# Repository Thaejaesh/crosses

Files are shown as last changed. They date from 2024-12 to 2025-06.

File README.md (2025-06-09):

# FORKED FROM ORIGINAL CREATOR: Good-Great-Grand-Wonderful @ https://github.com/Good-Great-Grand-Wonderful/crosses
# Crosses
_DSF2417

A modular ergonomic columar staggered keyboard by Good Great Grand Wonderful LLC. 

Made with a precise trackball sensor. Eliminating the need to have another pointing device, everything is within reach.

Available at http://ergokeyboards.com

### Features

- Matrix with a thumb cluster that works better with our opposable thumbs!
- Main matrix layouts of: 3x5, 3x6, and 4x6
- Kailh Choc hotswap sockets, so you can explore and find your perfect switch
- Left/Right or dualing trackballs
- Optional OLED screens

### Firmware

QMK: https://github.com/Good-Great-Grand-Wonderful/qmk_firmware/tree/gggw/crosses

Vial: https://github.com/Good-Great-Grand-Wonderful/crosses-vial-qmk/tree/gggw/crosses

ZMK(testing): https://github.com/Good-Great-Grand-Wonderful/crosses-zmk

### Gerbers

Production ready and prepped with JLCPCB part numbers: [Gerbers](Gerbers)

### BOM

#### Cases

N = Number of trackballs

| Qty |3x5 | 3x6 | 4x6 | Item | Notes |
|---|----|-----|-----|---|---|
| 24 | x  | x | x | 3mm Heat set inserts | |
| 16 | x  | x | x | 3mm x 5mm Hex Bolts | +2 for every trackball you delete |
| 2xN | x  | x | x | 3mm x 12mm Hex Bolts | |
| 2xN | x  | x | x | 3mm x 8mm Hex Bolts | |
| 1 | x  | x | x | Thumb Cluster PCB Panel | |
| 4 | x  | x | x | Hirose FH12-14S 0.5SH 1x14 1MP P0.50mm Horizontal | |
| 2 | x  | x | x | SM06B-SRSS-TB(LF)(SN) | |
| 1 | x  | | | 3x5 Matrix PCB Panel | |
| 1 | | x | | 3x6 Matrix PCB Panel | |
| 1 | | | x | 4x6 Matrix PCB Panel | |
| 2 | x  | | | 100mm 14p 0.5mm pitch FFC cables | |
| 2 | | x | x | 150mm 14p 0.5mm pitch FFC cables | |
| 1xN | x  | x | x | 100mm 6p JST SH 1.0 Same direction cables | |
| 2x | x  | x | x | Thumb Cluster Case (one should be flipped) | |
| 2x | x  | | | 3x5 Matrix Case (one should be flipped) | |
| 2x | | x | | 3x6 Matrix Case (one should be flipped) | |
| 2x | | | x | 4x6 Matrix Case (one should be flipped) | |
| 36x | x  | | | Kailh Choc Hotswap Sockets | |
| 42x | | x | | Kailh Choc Hotswap Sockets | |
| 54x | | | x | Kailh Choc Hotswap Sockets | |
| 36x | x  | | | 1N4148 SMD SOD-123 Resistors | |
| 42x | | x | | 1N4148 SMD SOD-123 Resistors | |
| 54x | | | x | 1N4148 SMD SOD-123 Resistors | |
| 1xN | x  | x | x | Trackball Mount (one should be flipped) | |
| 1xN | x  | x | x | Trackball PCB | [Repo](https://github.com/Good-Great-Grand-Wonderful/PMW3360DM-T2QU) |
| 1xN | x  | x | x | PMW3360DM-T2QU + LM19-LSI | or sub a PMW3389 |
| 1xN | x  | x | x | Trackball Carrier Base | |
| 1xN | x  | x | x | Trackball Carrier Top | |

## License



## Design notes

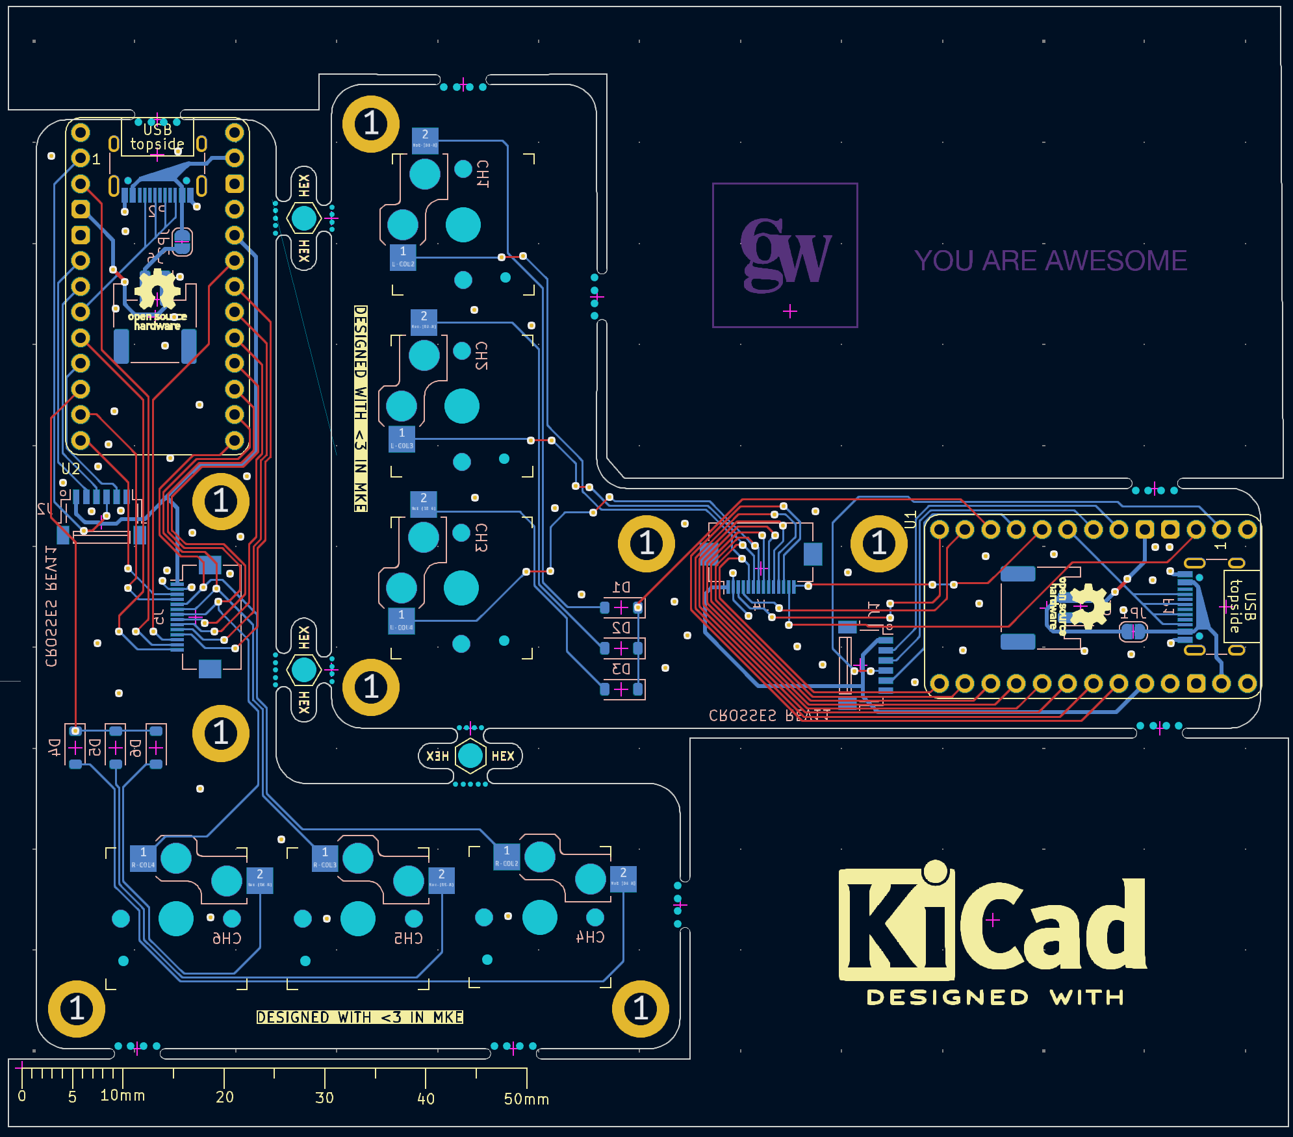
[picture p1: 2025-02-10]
Gerbers/thumbs-rev2-firmware-alpha/R11.png

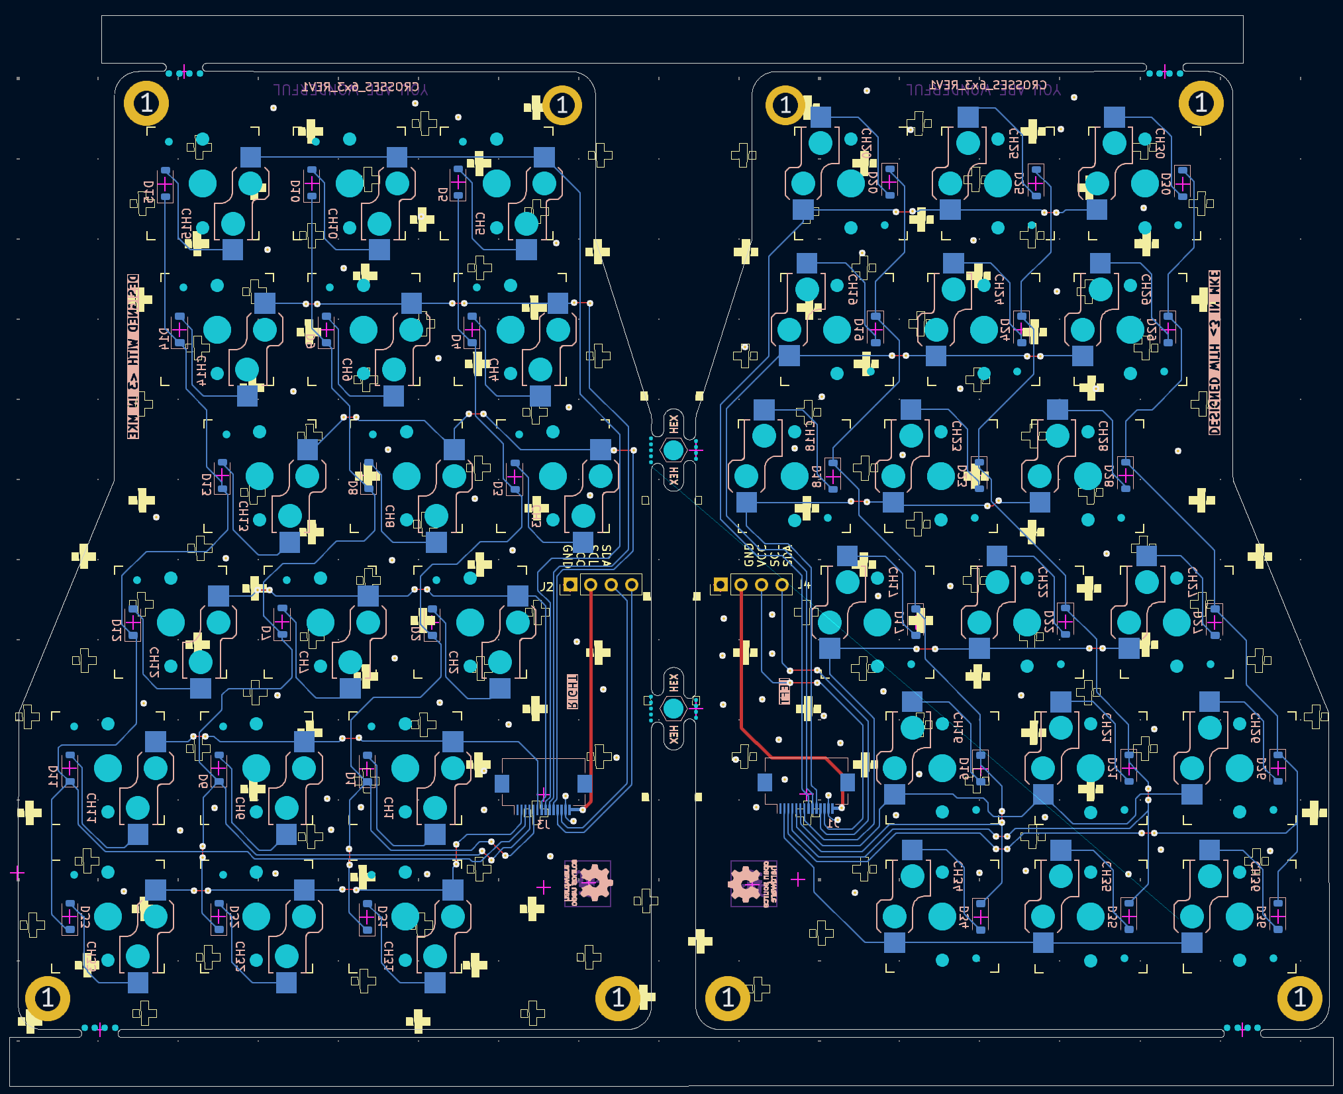
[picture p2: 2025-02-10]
Gerbers/matrix-6x3/6x3.png

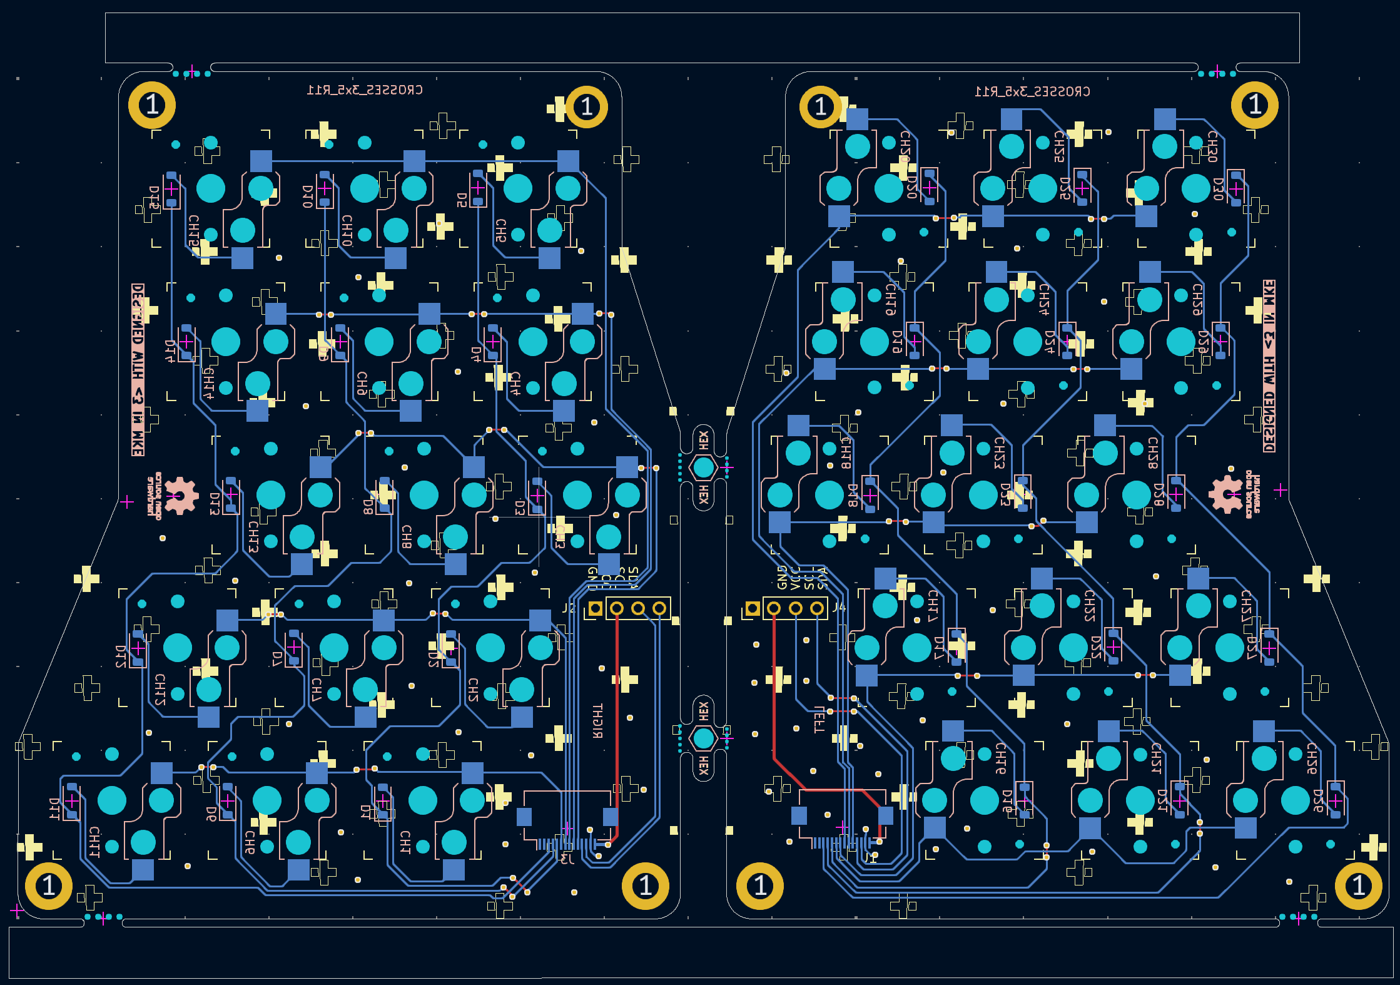
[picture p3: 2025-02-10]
Gerbers/matrix-5x3/5x3.png

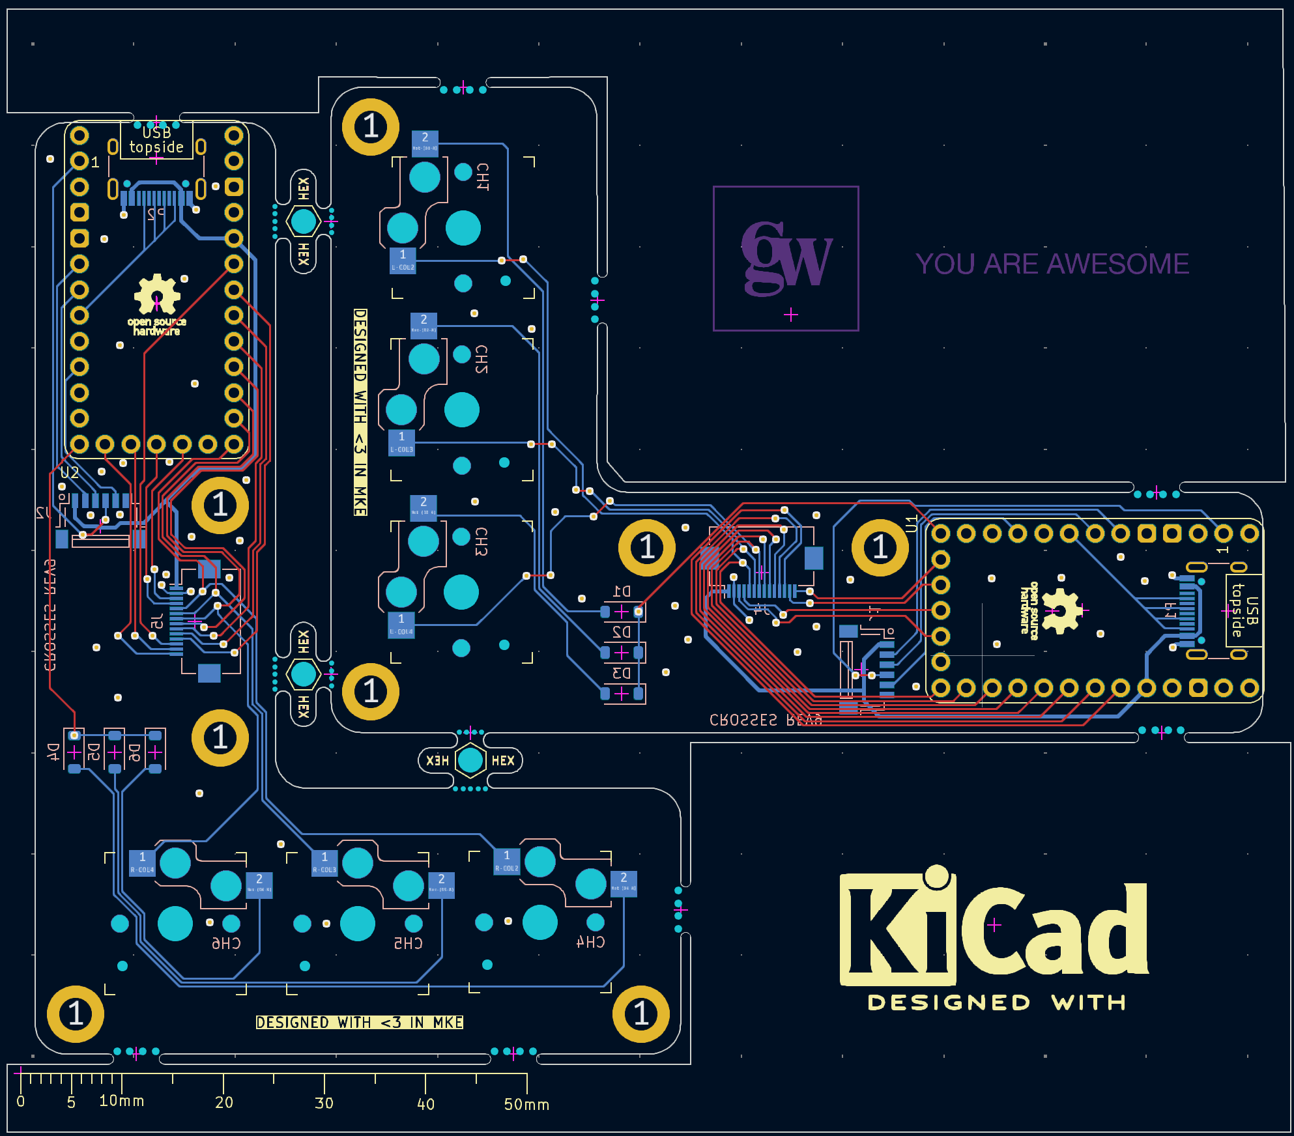
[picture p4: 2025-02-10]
Gerbers/thumbs-rev1-firmware/Rev9.png

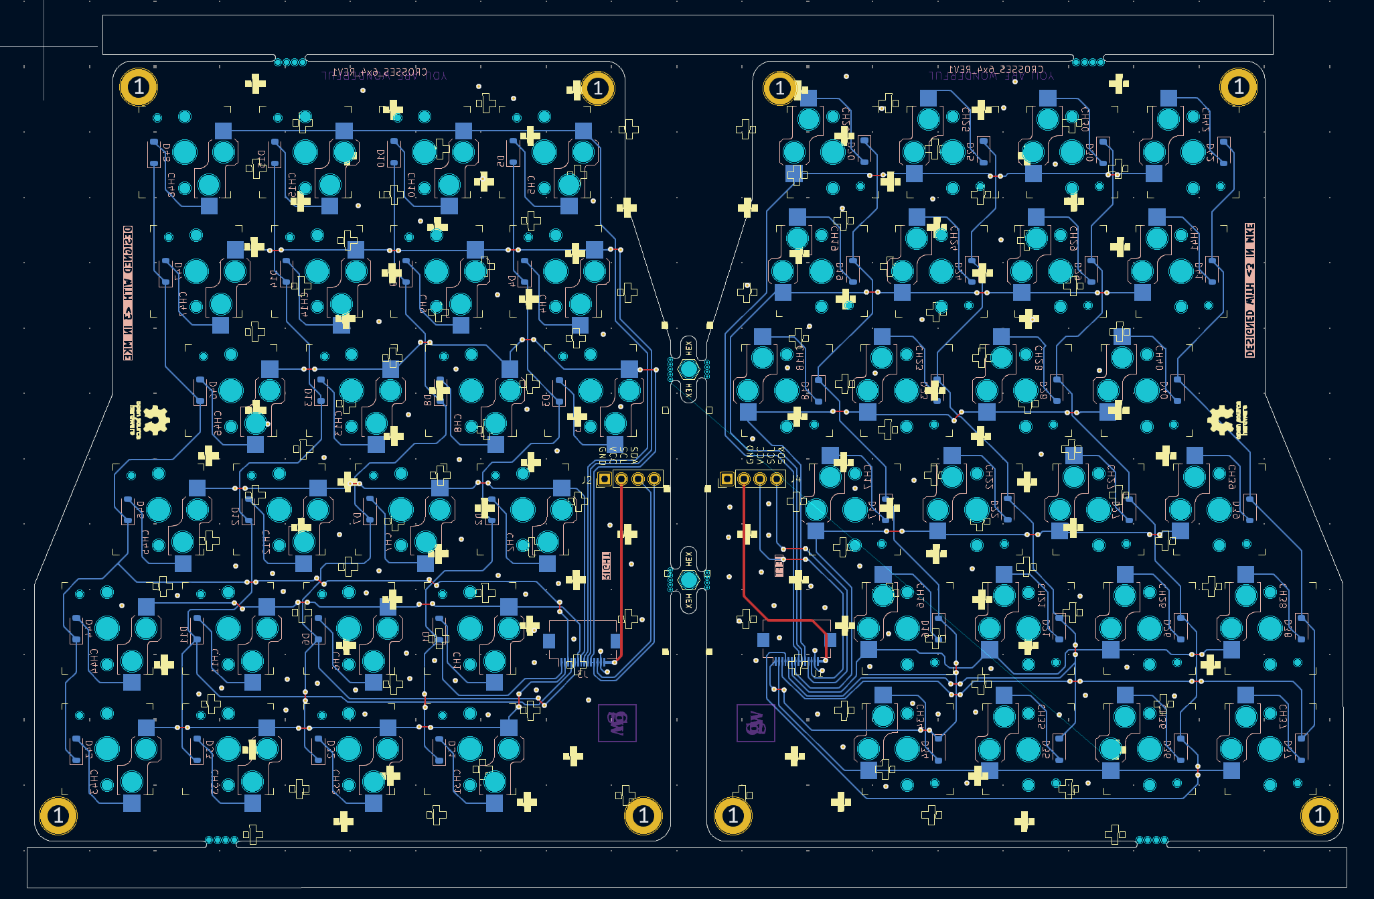
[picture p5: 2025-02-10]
Gerbers/matrix-6x4/6x4.png

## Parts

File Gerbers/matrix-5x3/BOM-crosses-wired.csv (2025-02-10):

Comment | Designator | Footprint | LCSC | Quantity
Conn_01x14_Pin | J1,J3 | Hirose_FH12-14S-0.5SH_1x14-1MP_P0.50mm_Horizontal | C5378715 | 2
1N4148 | D1,D10,D11,D12,D13,D14,D15,D16,D17,D18,D19,D2,D20,D21,D22,D23,D24,D25,D26,D27,D28,D29,D3,D30,D4,D5,D6,D7,D8,D9 | D_SOD-123 | C81598 | 30

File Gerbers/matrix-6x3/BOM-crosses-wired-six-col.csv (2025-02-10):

Comment | Designator | Footprint | LCSC | Quantity
Conn_01x14_Pin | J1,J3 | Hirose_FH12-14S-0.5SH_1x14-1MP_P0.50mm_Horizontal | C5378715 | 2
1N4148 | D1,D10,D11,D12,D13,D14,D15,D16,D17,D18,D19,D2,D20,D21,D22,D23,D24,D25,D26,D27,D28,D29,D3,D30,D31,D32,D33,D34,D35,D36,D4,D5,D6,D7,D8,D9 | D_SOD-123 | C81598 | 36
MountingHole | H3 | MountingHole_3.2mm_M3_DIN965_Pad |  | 1
MountingHole | H1 | MountingHole_3.2mm_M3_DIN965_Pad |  | 1
MountingHole | H6 | MountingHole_3.2mm_M3_DIN965_Pad |  | 1
MountingHole | H5 | MountingHole_3.2mm_M3_DIN965_Pad |  | 1

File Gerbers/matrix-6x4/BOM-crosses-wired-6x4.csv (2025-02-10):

Comment | Designator | Footprint | LCSC | Quantity
Conn_01x14_Pin | J1,J3 | Hirose_FH12-14S-0.5SH_1x14-1MP_P0.50mm_Horizontal | C5378715 | 2
1N4148 | D1,D10,D11,D12,D13,D14,D15,D16,D17,D18,D19,D2,D20,D21,D22,D23,D24,D25,D26,D27,D28,D29,D3,D30,D31,D32,D33,D34,D35,D36,D37,D38,D39,D4,D40,D41,D42,D43,D44,D45,D46,D47,D48,D5,D6,D7,D8,D9 | D_SOD-123 | C81598 | 48
MountingHole | H3 | MountingHole_3.2mm_M3_DIN965_Pad |  | 1
MountingHole | H1 | MountingHole_3.2mm_M3_DIN965_Pad |  | 1
MountingHole | H6 | MountingHole_3.2mm_M3_DIN965_Pad |  | 1
MountingHole | H5 | MountingHole_3.2mm_M3_DIN965_Pad |  | 1

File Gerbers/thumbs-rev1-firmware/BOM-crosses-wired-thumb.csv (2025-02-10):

Comment | Designator | Footprint | LCSC | Quantity
TYPE-C-31-M-12 USB | P1,P2 | USB_C_Receptacle_HRO_TYPE-C-31-M-12 | C165948 | 2
Conn_01x14_Pin | J4,J5 | Hirose_FH12-14S-0.5SH_1x14-1MP_P0.50mm_Horizontal | C5378715 | 2
1N4148 | D1,D2,D3,D4,D5,D6 | D_SOD-123 | C81598 | 6
MountingHole | H3 | MountingHole_3.2mm_M3_DIN965_Pad |  | 1
MountingHole | H1 | MountingHole_3.2mm_M3_DIN965_Pad |  | 1
MountingHole | H2 | MountingHole_3.2mm_M3_DIN965_Pad |  | 1

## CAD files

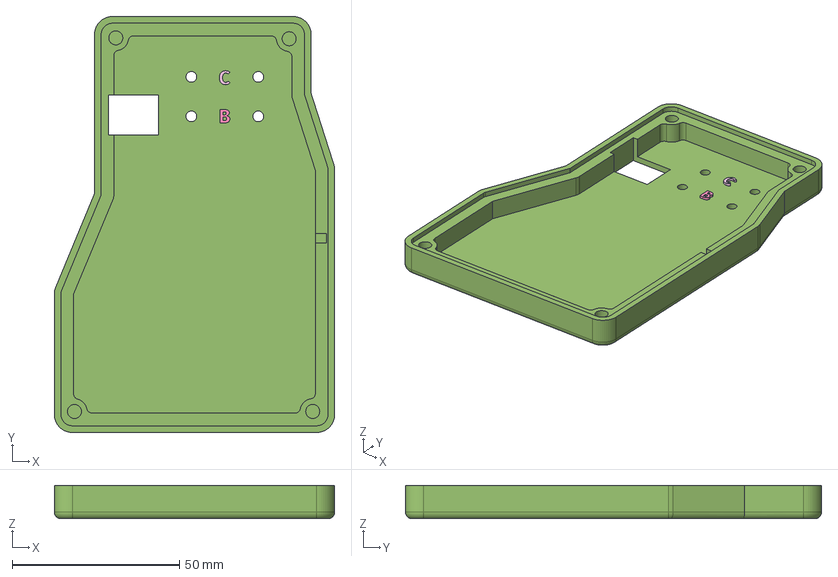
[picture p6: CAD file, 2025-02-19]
models/MatrixCase-3x6.step
83.8 x 124.3 x 10.0 mm

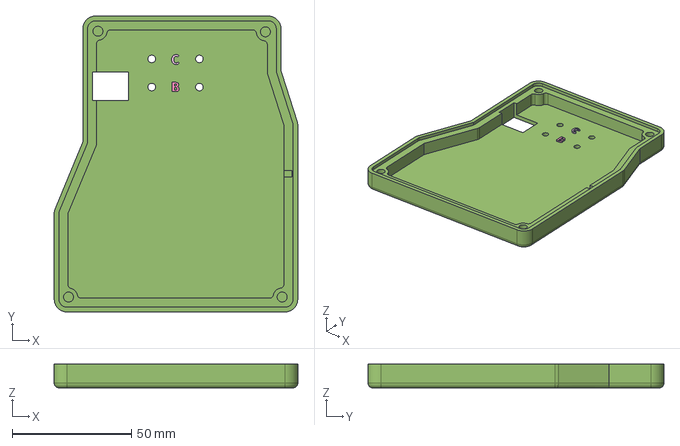
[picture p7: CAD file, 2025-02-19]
models/MatrixCase-4x6.step
102.3 x 124.3 x 10.0 mm

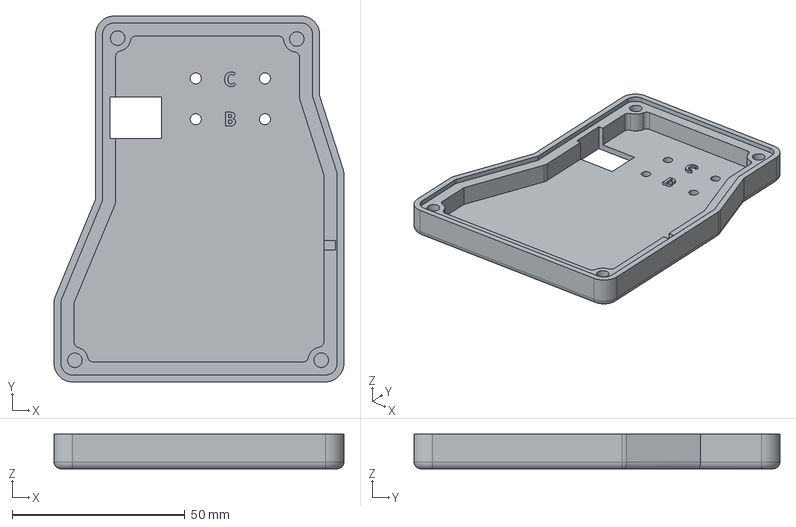
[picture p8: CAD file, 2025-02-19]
models/MatrixCase-3x5.step
83.8 x 105.8 x 10.0 mm

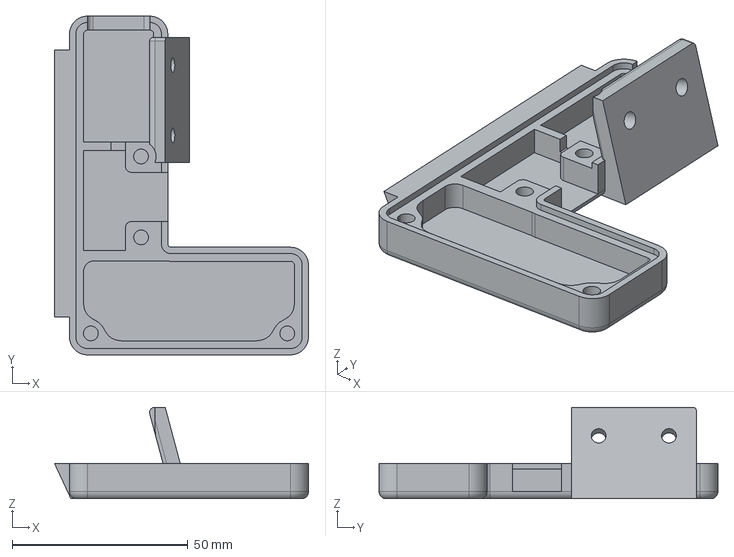
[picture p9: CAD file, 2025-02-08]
models/Crosses-Thumbcluster.step
72.2 x 96.3 x 26.0 mm

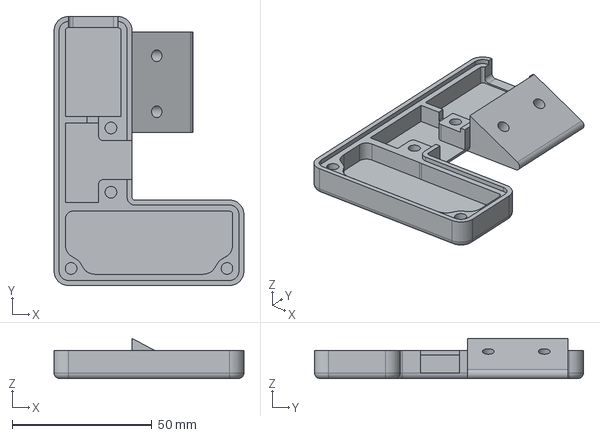
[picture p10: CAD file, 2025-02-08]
models/Bridges-Thumbcluster.step
67.9 x 96.3 x 14.4 mm

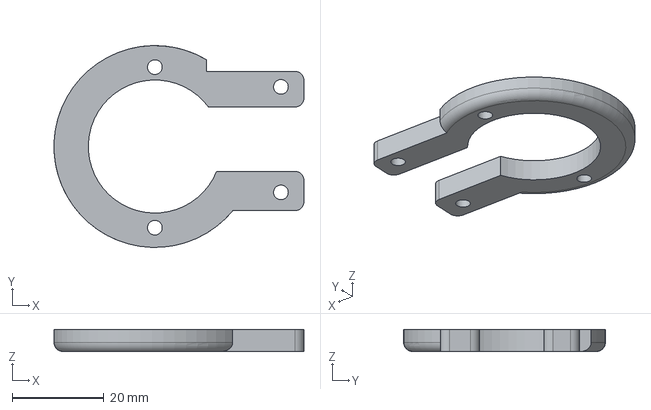
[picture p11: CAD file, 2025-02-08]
models/Bridges-Trackball-Mount.step
54.5 x 44.0 x 4.80 mm

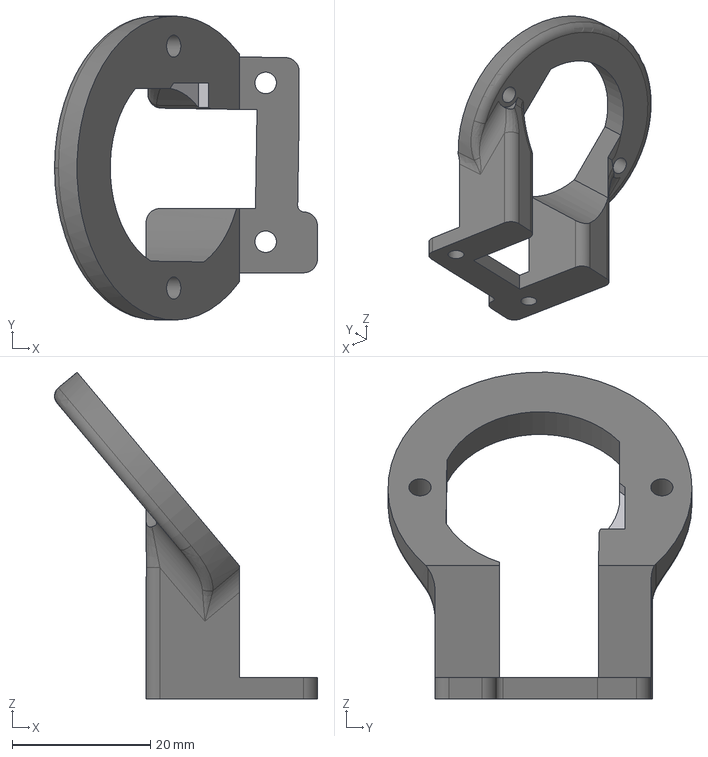
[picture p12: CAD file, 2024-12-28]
models/Crosses-Trackball-Mount.step
38.1 x 44.0 x 47.3 mm

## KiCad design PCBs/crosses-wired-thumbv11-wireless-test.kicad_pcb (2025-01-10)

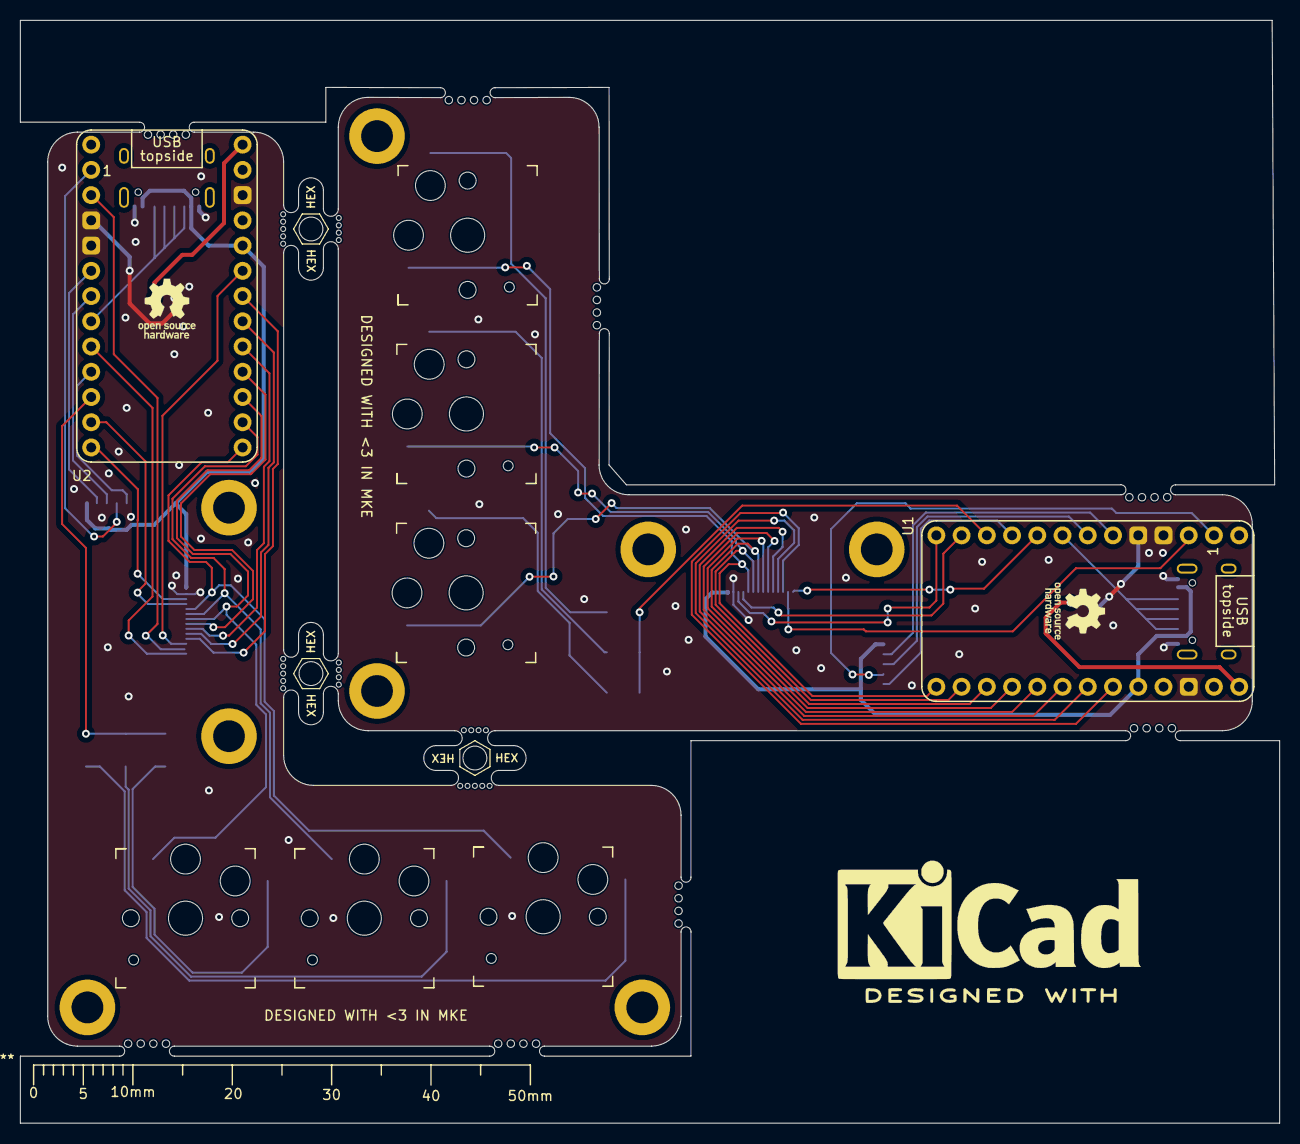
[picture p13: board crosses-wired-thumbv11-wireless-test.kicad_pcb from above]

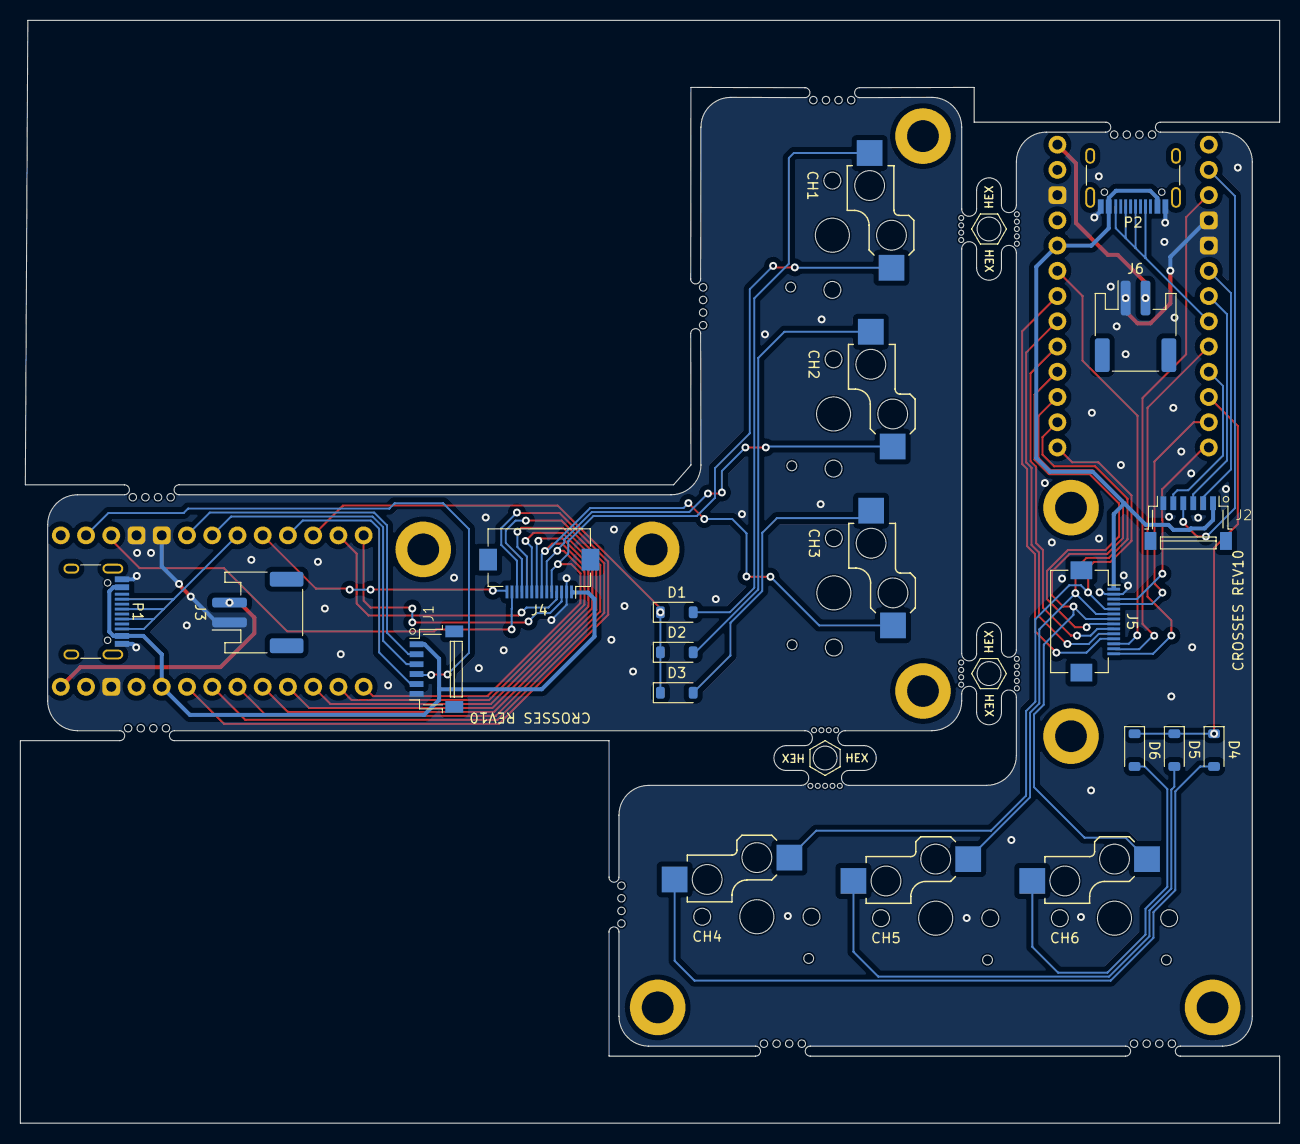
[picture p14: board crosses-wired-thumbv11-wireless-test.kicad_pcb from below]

Board: 2 copper layers, 126.8 x 111.0 mm, 33 parts (18 on the bottom side), 47 nets.

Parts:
CH1, CH2, CH3, CH4, CH5, CH6: CPG135001S30; Kailh_socket_PG1350
D1, D2, D3, D4, D5, D6: 1N4148; D_SOD-123
H1, H1#2, H2, H2#2, H3, H3#2, H3#3, H3#4: MountingHole; MountingHole_3.2mm_M3_DIN965_Pad
J1, J2: SM06B-SRSS-TB(LF)(SN)
J3, J6: Conn_01x02_Socket; JST_PH_S2B-PH-SM4-TB_1x02-1MP_P2.00mm_Horizontal
J4, J5: Conn_01x14_Pin; Hirose_FH12-14S-0.5SH_1x14-1MP_P0.50mm_Horizontal
MB5, MB5#2, MB5#3: 5.5mm; mousebites_5p5mm_easysnap
P1, P2: TYPE-C-31-M-12 USB; USB_C_Receptacle_HRO_TYPE-C-31-M-12
U1, U2: supermini nrf / nice nano v2; Helios_AH_USBup

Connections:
GND: J1.6, J2.6, J3.1, J4.2, J5.2, J6.1, P1.A1 (GND), P1.A12 (GND), P1.B1 (GND), P1.B12 (GND), P2.A1 (GND), P2.A12 (GND), P2.B1 (GND), P2.B12 (GND), U1.3 (GND), U1.4 (GND), U1.14 (GND), U2.3 (GND), U2.4 (GND), U2.14 (GND)
L-COL0: J4.9, U1.20 (F7)
L-COL1: J4.8, U1.21 (B1)
L-COL2: CH1.1, J4.5, U1.24 (B6)
L-COL3: CH2.1, J4.6, U1.23 (B2)
L-COL4: CH3.1, J4.7, U1.22 (B3)
L-COLP: J4.13, U1.2 (D2-RX)
L-CS: J1.5, U1.9 (D7)
L-DATA: P1.A5 (CC1), P1.A6 (D+), P1.B5 (CC2), P1.B6 (D+), U1.7 (D4)
L-I2C SCL: J4.3, U1.12 (B5)
L-I2C SDA: J4.4, U1.11 (B4)
L-MISO: J1.4, U1.1 (D3-TX)
L-MOSI: J1.3, U1.6 (D0)
L-ROW0: J4.10, U1.19 (F6)
L-ROW1: J4.11, U1.18 (F5)
L-ROW2: J4.12, U1.17 (F4)
L-ROW3: D1.1 (K), D2.1 (K), D3.1 (K), U1.10 (E6)
L-ROWH: J4.14, U1.8 (C6)
L-SCK: J1.2, U1.5 (D1)
L-VCC: J1.1, J4.1, P1.A4 (VBUS), P1.A9 (VBUS), P1.B4 (VBUS), P1.B9 (VBUS), U1.16 (VCC)
unnamed: CH1.2, D1.2 (A)
unnamed: CH2.2, D2.2 (A)
unnamed: CH3.2, D3.2 (A)
unnamed: CH4.2, D4.2 (A)
unnamed: CH5.2, D5.2 (A)
unnamed: CH6.2, D6.2 (A)
R-COL0: J5.9, U2.20 (F7)
R-COL1: J5.8, U2.21 (B1)
R-COL2: CH4.1, J5.5, U2.24 (B6)
R-COL3: CH5.1, J5.6, U2.23 (B2)
R-COL4: CH6.1, J5.7, U2.22 (B3)
R-COLP: J5.13, U2.2 (D2-RX)
R-CS: J2.5, U2.9 (D7)
R-DATA: P2.A5 (CC1), P2.A6 (D+), P2.B5 (CC2), P2.B6 (D+), U2.7 (D4)
R-I2C SCL: J5.3, U2.12 (B5)
R-I2C SDA: J5.4, U2.11 (B4)
R-MISO: J2.4, U2.1 (D3-TX)
R-MOSI: J2.3, U2.6 (D0)
R-ROW0: J5.10, U2.19 (F6)
R-ROW1: J5.11, U2.18 (F5)
R-ROW2: J5.12, U2.17 (F4)
R-ROW3: D4.1 (K), D5.1 (K), D6.1 (K), U2.10 (E6)
R-ROWH: J5.14, U2.8 (C6)
R-SCK: J2.2, U2.5 (D1)
R-VCC: J2.1, J5.1, P2.A4 (VBUS), P2.A9 (VBUS), P2.B4 (VBUS), P2.B9 (VBUS), U2.16 (VCC)
VBATTL: J3.2, U1.30 (VBUS)
VBATTR: J6.2, U2.30 (VBUS)

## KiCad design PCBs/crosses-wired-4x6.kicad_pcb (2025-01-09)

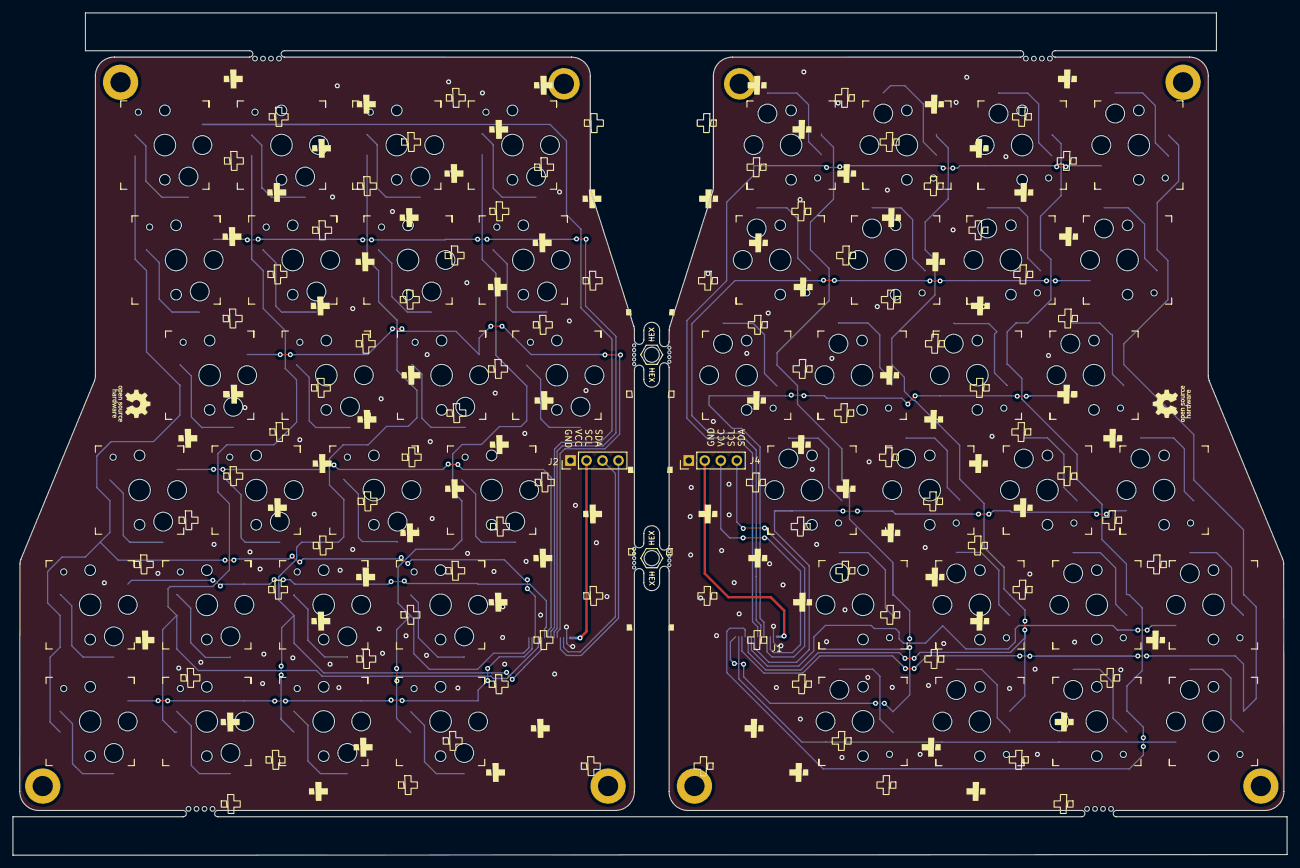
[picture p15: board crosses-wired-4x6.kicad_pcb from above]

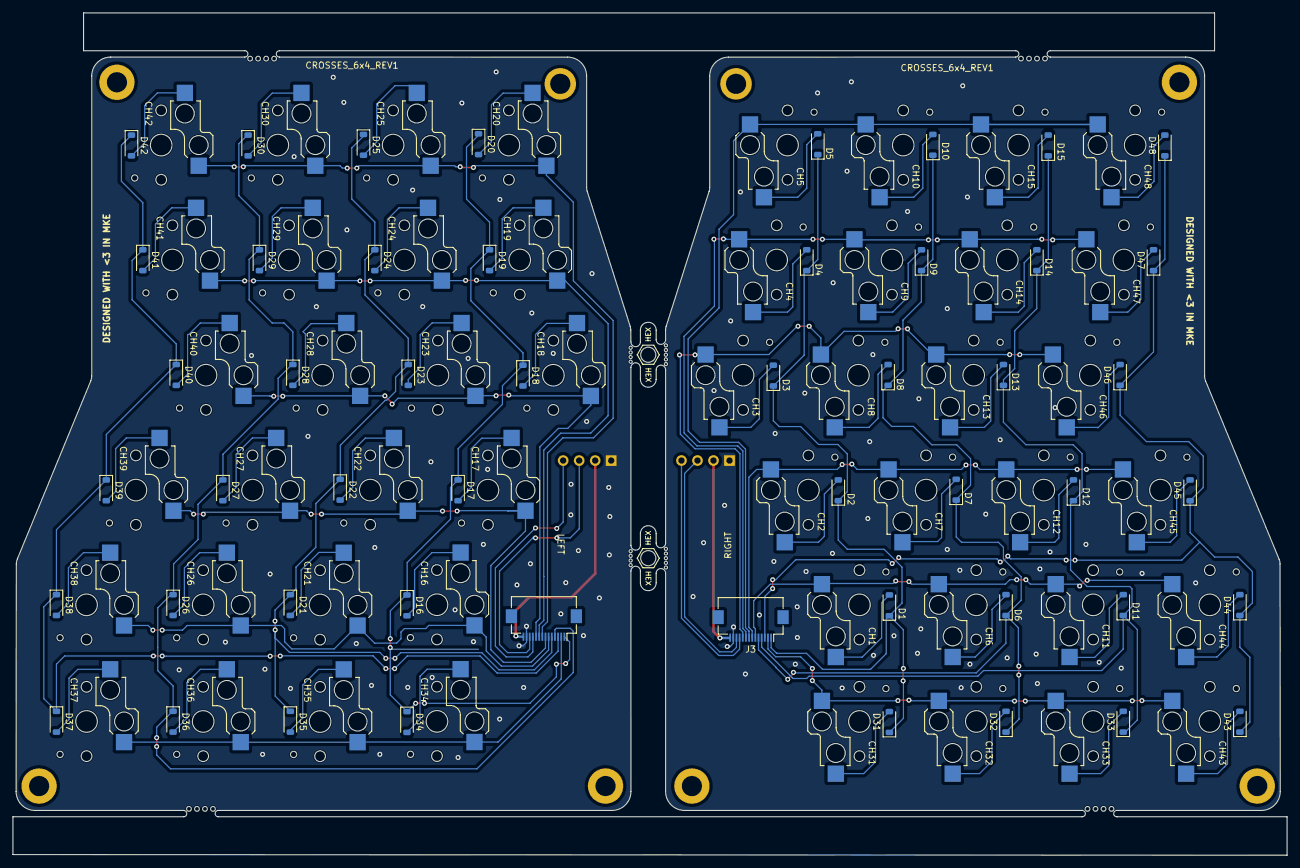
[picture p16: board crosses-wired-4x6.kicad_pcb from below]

Board: 2 copper layers, 202.1 x 133.6 mm, 110 parts (54 on the bottom side), 75 nets.

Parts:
CH1, CH2, CH3, CH4, CH5, CH6, CH7, CH8, CH9, CH10, CH11, CH12, CH13, CH14, CH15, CH16, CH17, CH18, CH19, CH20, CH21, CH22, CH23, CH24, CH25, CH26, CH27, CH28, CH29, CH30, CH31, CH32, CH33, CH34, CH35, CH36, CH37, CH38, CH39, CH40, CH41, CH42, CH43, CH44, CH45, CH46, CH47, CH48: CPG135001S30; Kailh_socket_PG1350
D1, D2, D3, D4, D5, D6, D7, D8, D9, D10, D11, D12, D13, D14, D15, D16, D17, D18, D19, D20, D21, D22, D23, D24, D25, D26, D27, D28, D29, D30, D31, D32, D33, D34, D35, D36, D37, D38, D39, D40, D41, D42, D43, D44, D45, D46, D47, D48: 1N4148; D_SOD-123
H1, H1#2, H3, H3#2, H5, H5#2, H6, H6#2: MountingHole; MountingHole_3.2mm_M3_DIN965_Pad
J1, J3: Conn_01x14_Pin; Hirose_FH12-14S-0.5SH_1x14-1MP_P0.50mm_Horizontal
J2, J4: Conn_01x04_Socket; PinHeader_1x04_P2.54mm_Vertical
MB5, MB5#2: 5.5mm; mousebites_5p5mm_easysnap

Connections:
GND: J1.13, J2.1, J3.13, J4.1
L-COL0: CH1.1, CH6.1, CH11.1, CH44.1, J3.6
L-COL1: CH2.1, CH7.1, CH12.1, CH45.1, J3.7
L-COL2: CH3.1, CH8.1, CH13.1, CH46.1, J3.10
L-COL3: CH4.1, CH9.1, CH14.1, CH47.1, J3.9
L-COL4: CH5.1, CH10.1, CH15.1, CH48.1, J3.8
L-COLP: CH31.1, CH32.1, CH33.1, CH43.1, J3.2
L-ROW0: D6.1 (K), D7.1 (K), D8.1 (K), D9.1 (K), D10.1 (K), D32.1 (K), J3.5
L-ROW1: D11.1 (K), D12.1 (K), D13.1 (K), D14.1 (K), D15.1 (K), D33.1 (K), J3.4
L-ROW2: D43.1 (K), D44.1 (K), D45.1 (K), D46.1 (K), D47.1 (K), D48.1 (K), J3.3
L-ROW-N1: D1.1 (K), D2.1 (K), D3.1 (K), D4.1 (K), D5.1 (K), D31.1 (K), J3.1
unnamed: CH1.2, D1.2 (A)
unnamed: CH2.2, D2.2 (A)
unnamed: CH3.2, D3.2 (A)
unnamed: CH4.2, D4.2 (A)
unnamed: CH5.2, D5.2 (A)
unnamed: CH6.2, D6.2 (A)
unnamed: CH7.2, D7.2 (A)
unnamed: CH8.2, D8.2 (A)
unnamed: CH9.2, D9.2 (A)
unnamed: CH10.2, D10.2 (A)
unnamed: CH11.2, D11.2 (A)
unnamed: CH12.2, D12.2 (A)
unnamed: CH13.2, D13.2 (A)
unnamed: CH14.2, D14.2 (A)
unnamed: CH15.2, D15.2 (A)
unnamed: CH16.2, D16.2 (A)
unnamed: CH17.2, D17.2 (A)
unnamed: CH18.2, D18.2 (A)
unnamed: CH19.2, D19.2 (A)
unnamed: CH20.2, D20.2 (A)
unnamed: CH21.2, D21.2 (A)
unnamed: CH22.2, D22.2 (A)
unnamed: CH23.2, D23.2 (A)
unnamed: CH24.2, D24.2 (A)
unnamed: CH25.2, D25.2 (A)
unnamed: CH26.2, D26.2 (A)
unnamed: CH27.2, D27.2 (A)
unnamed: CH28.2, D28.2 (A)
unnamed: CH29.2, D29.2 (A)
unnamed: CH30.2, D30.2 (A)
unnamed: CH31.2, D31.2 (A)
unnamed: CH32.2, D32.2 (A)
unnamed: CH33.2, D33.2 (A)
unnamed: CH34.2, D34.2 (A)
unnamed: CH35.2, D35.2 (A)
unnamed: CH36.2, D36.2 (A)
unnamed: CH37.2, D37.2 (A)
unnamed: CH38.2, D38.2 (A)
unnamed: CH39.2, D39.2 (A)
unnamed: CH40.2, D40.2 (A)
unnamed: CH41.2, D41.2 (A)
unnamed: CH42.2, D42.2 (A)
unnamed: CH43.2, D43.2 (A)
unnamed: CH44.2, D44.2 (A)
unnamed: CH45.2, D45.2 (A)
unnamed: CH46.2, D46.2 (A)
unnamed: CH47.2, D47.2 (A)
unnamed: CH48.2, D48.2 (A)
R-COL0: CH16.1, CH21.1, CH26.1, CH38.1, J1.6
R-COL1: CH17.1, CH22.1, CH27.1, CH39.1, J1.7
R-COL2: CH18.1, CH23.1, CH28.1, CH40.1, J1.10
R-COL3: CH19.1, CH24.1, CH29.1, CH41.1, J1.9
R-COL4: CH20.1, CH25.1, CH30.1, CH42.1, J1.8
R-COLP: CH34.1, CH35.1, CH36.1, CH37.1, J1.2
R-ROW0: D21.1 (K), D22.1 (K), D23.1 (K), D24.1 (K), D25.1 (K), D35.1 (K), J1.5
R-ROW1: D26.1 (K), D27.1 (K), D28.1 (K), D29.1 (K), D30.1 (K), D36.1 (K), J1.4
R-ROW2: D37.1 (K), D38.1 (K), D39.1 (K), D40.1 (K), D41.1 (K), D42.1 (K), J1.3
R-ROW-N1: D16.1 (K), D17.1 (K), D18.1 (K), D19.1 (K), D20.1 (K), D34.1 (K), J1.1
SCL: J2.3, J3.12
SCL-R: J1.12, J4.3
SDA: J2.4, J3.11
SDA-R: J1.11, J4.4
VCC: J2.2, J3.14
VCC-R: J1.14, J4.2

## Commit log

2024-12-28 [CHORE] Adding models
    [MatrixCase-3x5.step, MatrixCase-3x6.step, Thumb-Cluster.step]
2024-12-28 [MINOR] Adding trackball mount
    [Trackball-Mount.step]
2025-01-03 Add 4x6, add new version of thumb cluster
    [MatrixCase-4x6.step, Thumb-Cluster.step]
2025-01-09 Adding PCBs
    [crosses-wired-3x5.kicad_pcb, crosses-wired-3x6l.kicad_pcb, crosses-wired-6x4.kicad_pcb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]
2025-01-09 Add OSH logos
    [crosses-wired-3x5.kicad_pcb, crosses-wired-3x6.kicad_pcb, crosses-wired-4x6.kicad_pcb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]
2025-01-10 Adding test wireless PCB
    [crosses-wired-thumbv11-wireless-test.kicad_pcb]
2025-01-14 Updating case designs
    [MatrixCase-3x5.step, MatrixCase-3x6.step, MatrixCase-4x6.step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]
2025-01-15 Updating models
    [MatrixCase-3x5.step, MatrixCase-3x6.step, MatrixCase-4x6.step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]
2025-02-08 Adding Bridges models
    [Bridges-Thumbcluster.step, Bridges-Trackball-Mount.step, Crosses-Thumbcluster.step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]
2025-02-10 Adding production gerbers
    [BOM-crosses-wired-6x4.csv, BOM-crosses-wired-six-col.csv, BOM-crosses-wired-thumb.csv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]
2025-02-14 Updating 4x6
    [MatrixCase-4x6.step]
2025-02-19 [MINOR] Add variant indicators to cases
    [MatrixCase-3x5.step, MatrixCase-3x6.step, MatrixCase-4x6.step]

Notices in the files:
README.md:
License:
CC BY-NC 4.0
